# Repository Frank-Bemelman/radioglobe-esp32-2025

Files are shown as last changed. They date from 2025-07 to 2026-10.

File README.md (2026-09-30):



# radioglobe-esp32-2025
Radio Globe using ESP32S3 and Waveshare round touch LCD 2.1 inch<br><br>
UPDATE 29-SEP-2026<br>Changed the file playing progress bar into a slider bar. With this you can move backward/forward through the file playing.<br><br>
UPDATE 21-SEP-2026<br>Improved accuracy of progress bar, compensating for embedded artwork and metadata in music files.<br><br>
UPDATE 19-SEP-2026<br>Added a progress bar for playing files from SD card.<br><br>
UPDATE 5-SEP-2026<br>Several bug fixes and many improvements behind the scenes.<br><br>
UPDATE 2-AUG-2026<br>Improvements regarding fetching timezone(s) and updating the country flags. Should all be a little snappier now.<br><br>
UPDATE 1-AUG-2026<br>Added a new fun feature. When you touch the weather icon, a flight radar screen is shown, with airplanes in that area. Not much particulary usful, but just for fun.<br><br>
UPDATE 27-JUL-2026<br>New station150K.json file upload. Removed all station url's that are no longer active. This also improves the experience with the globe, no more skipping of stations that are no longer active. Used a long running script to test all url's.<br><br>
UPDATE 15-JUL-2026<br>Improved handling of retrieving timezone and geolocation. Race conditions could occur, now hopefully solved. Battery percentage indicator, better than that silly voltage level. <br><br>
UPDATE 12-JUL-2026<br>Automatic Auto Power Off. If you only set the volume to 0, the globe keeps streaming in the background. Which is a waste of bandwidth, for you and for the radio station. So, after 5 minutes, the globe switches off and the clock is shown. Also, after 8 hours normal playing but without any user interaction, the globe will turn the volume down and switches off silently.<br><br> 
UPDATE 7-JUL-2026<br>Switching between Radio and SD music files, can now be done by long pressing the RADIO GLOBE / MUSIC GLOBE text on the main screen. When playing SD card files, the actual path GLOBEMUSIC/xxxx is shown.<br><br>
UPDATE 5-JUL-2026<br>Added a Globe webserver to make it easier to add/delete music MP3 files. Navigate to radioglobe-XX.local where XX is the serialnumber of the globe.<br><br>
UPDATE 3-JUL-2026<br>Fixed a FTP bug as it refused to work with filenames containing single quotes<br><br>
UPDATE 2-JUL-2026<br>
Added FTP servers for globe and puck. For the puck, activate it with secret code BOBOB in setup menu. IP address will be shown once FTP server is launched. Use Filezilla, plain FTP, user globe password globe, transfer settings default, limit max connections 1.<br><br>
UPDATE 1-JUL-2026<br>
New stations150K.json file for the puck SD card. After you replace it, rebuild the database, in puck menu.<br><br>
UPDATE 1-JUL-2026<br>Added the ESP32_VS1053_Stream library files in the Arduino RADIOGLOBE-GLOBE project folder - these are slightly modified<br><br>
UPDATE 30-JUN-2026<br>Added auto update feature -> long press serial number in setup menu for auto update globe and puck<br><br>
UPDATE 24-MRT-2026<br>Added lots of features, worldmap, clock, weather status, currency exchange<br><br>
UPDATE 15-JULY-2025<br>Lots of improvements made. Most stations now play without issues. Happy with the result.<br><br>
UPDATE 6-JULY-2025<br>It actually works! Performance is improved, few bugs, some extras. <br><br>
UPDATE 1-JULY-2025<br>It actually works! Performance is perhaps not perfect but certainly acceptable.<br><br>

Not a small project, will take a lot of your time and possibly quite some frustration along the way. Just a gentle warning.

The idea of a 'Radio Globe' is not mine. I was inspired by the works of Jude Pullen. His brilliant design can be found here:
https://github.com/DesignSparkRS/RadioGlobe

Since I am more of an ESP32 guy, I decided to do a complete redesign. New design of 3d printable parts, which you find in de fusion-3d folder here.
You can use Fusion to select the body you want to print on your 3d printer. Or edit them if you wish. I am not very matured in Fusion, so the Fusion timeline is a nice mess.

The globe uses two ESP32 constantly talking to each other using ESPNOW. 

The first ESP32 is in the base of the globe, and deals with actual streaming of a internet radio station, encoders for the coordinates.
It also retrieving the timezone when new coordinates/position is chosen. The timezone is then sent back to the display puck.

The other ESP32 is part of the display puck. I used a Waveshare touch display 2.1 inch. The display puck deals
with volume control, display of what is going on, like coordinates, local time, station name, what song is playing etc. 
It communicates with the Globe's ESP32, using ESPNOW. It receives the exact coordinates NS and EW, remaps them 
as the globes you can buy aren't very accurate. It sends the remapped coordinates back to the globe. Together with the
remapped coordinates, it sends a radiostation url. The urls are stored on a micro SD card. 

There are two directories with source files. One for the globe and one for the display. It is all based on Arduino IDE 2.3.10

Essential hardware for the globe:<br/>
ESP32S3-N16R8 
MP3 decoder -> https://www.aliexpress.com/item/32893187079.html<br/>
2x magnetic encoder AS5600
<br/>
Essential hardware for the display:<br/>
ESP32S3 Waveshare 2.1 inch LCD -> https://www.aliexpress.com/item/1005008679530480.html<br/>
Lithium battery -> https://www.aliexpress.com/item/1005008575678945.html<br/>
2x Magnets 10mmx2mm
Pogo 3 pin connector -> https://www.aliexpress.com/item/1005007457425590.html<br/> 
MicroSD card -> I used a 32GB one<br/>

1) The 3D files can be send to jlcpcb.com. Best choices for base and puck are black nylon. For the main globe support, transparent resin is nice, but you need to spray them with a UV blocking varnish, as they tend yellow very quickly when placed near a window. The counterweight to be printed in metal, and if you want to use the truss as a touch sensor, also in metal.
   
3) Prepare the SD card and fill it with the files provided in SDCARD. This is for the database with 150K stations and two folders with images for the flags of all countries in the world. Insert the card in the Waveshare display. Once you have loaded the software into the Waveshare, you can create a presorted database arrangement in a folder structure on the SD card. This takes perhaps 45 minutes, but then you're good to go.

4) Prepare the ESP32 module with the software for the globe itself. Compile in Arduino IDE, don't forget to fill the secrets.h file with your wifi SSID and password.

5) Get an API key at Google Developer platform, for the TimeZone API and Geo Geocoding API, both use the same API key. It is used to find the right timezone for the clock, and also to get the right two-letter country code to be able to display the right country flag. It is a bit of hassle, but very worthwhile. And it is free.

I don't plan to give a step-by-step instruction here. That is too much effort and I don't know if there is a lot of interrest in this project. But if you start with it, just ask, simply raise as an issue. In which case I may elaborate a bit more.

Cheers,
Frank

[work in progress]

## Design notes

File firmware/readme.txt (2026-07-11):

Latest version has an easier auto update function. It will signal a new update is available, if the cogwheel setup button is red. 
Go into settings on the puck, long press the serial number and it will upgrade both globe and puck, using the bin files from the release. 
First the globe upgrades automatically, then the puck will upgrade also.
The puck display goes black during the upgrade, just hang in there for a few minutes - it will reboot after a few minutes.

HOWEVER!!! If your version does NOT have the auto-update feature yet, it takes a bit more work.
Good news is, you only have to do this once.

1) download the three bin files for globe (firmware) and puck (firmware and new partition table) as found in the release.
   These can all be uploaded using a chrome browser on PC and a webtool
2) Browse to: https://thelastoutpostworkshop.github.io/ESPConnect/
3) Connect Puck, use the blue connect button, select the USB port, and connect.
   Select Flash Tools on the left.
4) First flash the new partition file for the puck. Load it in the flashtool, select Recommended Offsets -> Partition Table • 0x8000 • 4 KB
   Hit the large FLASH FIRMWARE bar/button.
5) Load the RadioGlobe-Display.bin, select Recommended Offsets -> App0 0x10000 4MB
   Hit the large FLASH FIRMWARE bar/button.
6) Disconnect Puck, reset it with side button.
7) Check in the puck setup if the build date has been adjusted. If not, try again with App1 0x410000 4MB

8) Connect the Globe ESP32S3 to your PC. Use the blue connect button, select the USB port, and connect.
9) Load the RadioGlobe-Globe.bin, select Recommended Offsets -> App0 0x10000 3MB
   Hit the large FLASH FIRMWARE bar/button. 
10) Disconnect Globe and reset globe (power off-on).
11) Check in the puck setup if the globe build date has been adjusted. If not, try again with App1 0x310000 3MB

From now on, you can update automatically, no more fiddling with cables.
Everytime you power down/up the globe using the puck, it will check for an update and the cogwheel will turn red if there is one available.
You can also force a check for new updates, by long pressing the serial number in the setup menu.
During an automatic update the puck goes black, don't worry, it will come back after 2-3 minutes.

Enjoy & Good luck!

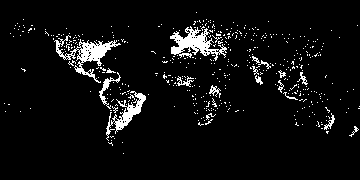
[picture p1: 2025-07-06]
source/squareline/assets/stationsmap150K.png

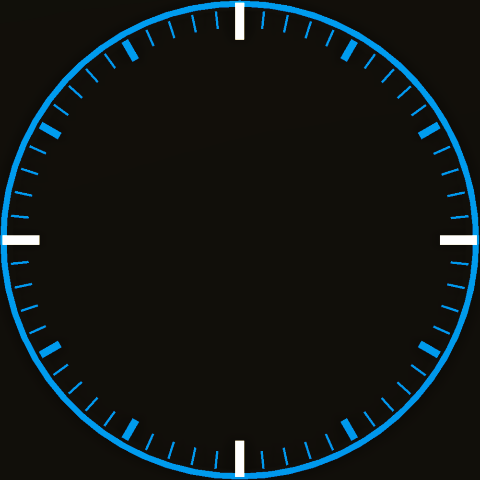
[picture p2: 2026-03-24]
source/squareline/assets/clock480.png

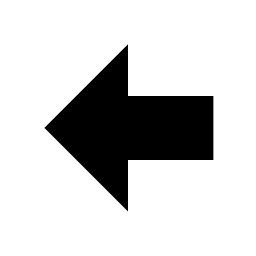
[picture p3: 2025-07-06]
source/squareline/assets/arrow_left_bold.png

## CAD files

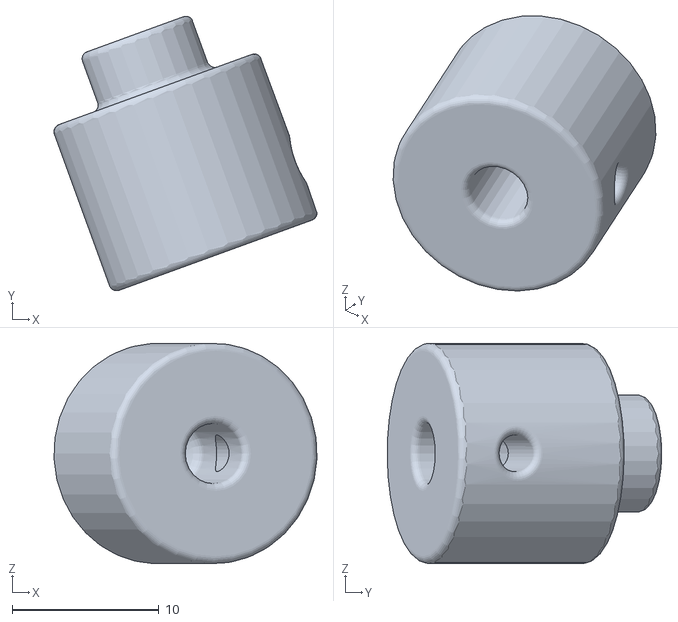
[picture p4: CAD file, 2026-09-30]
fusion-3d/main-shaft-magnet-holder.stl
17.9 x 18.7 x 15.0

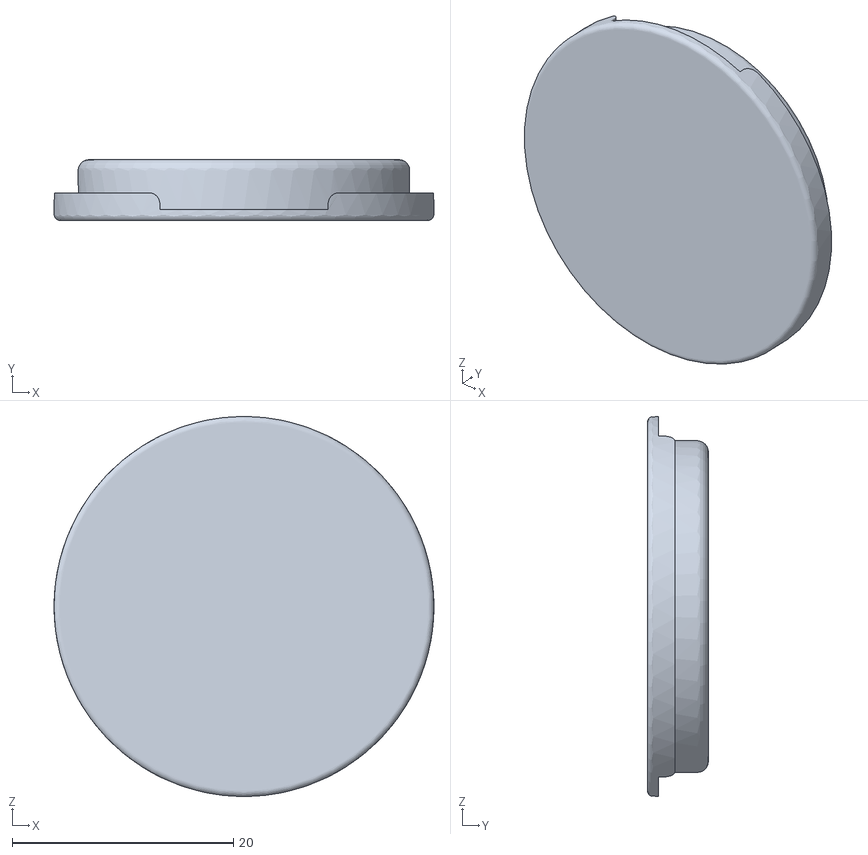
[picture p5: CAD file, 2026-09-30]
fusion-3d/globe-main-support-lid.stl
34.3 x 5.50 x 34.3

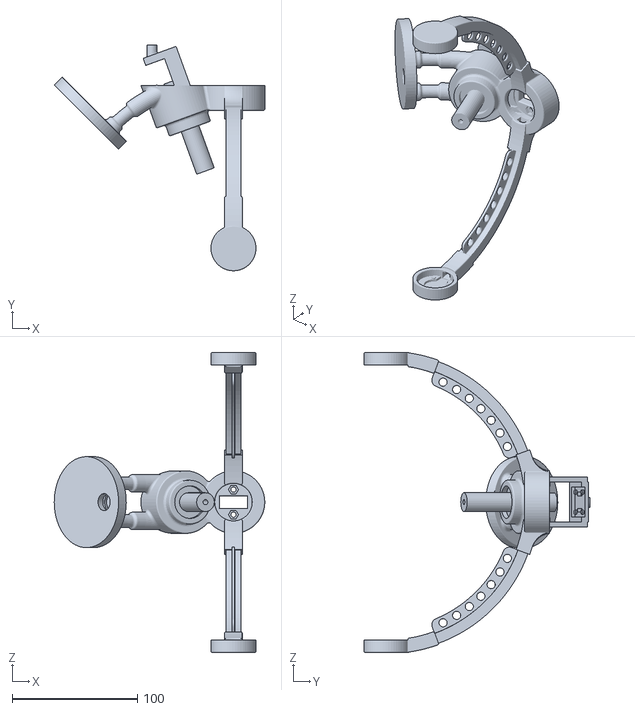
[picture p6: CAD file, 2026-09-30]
fusion-3d/globe-main-support.stl
168.0 x 180.0 x 239.4

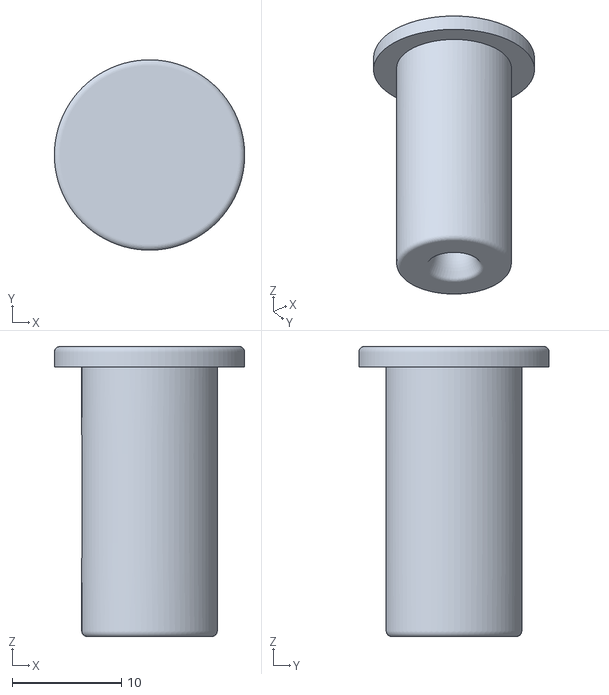
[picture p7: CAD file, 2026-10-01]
fusion-3d/globe-bushing-top.stl
17.4 x 17.4 x 26.5

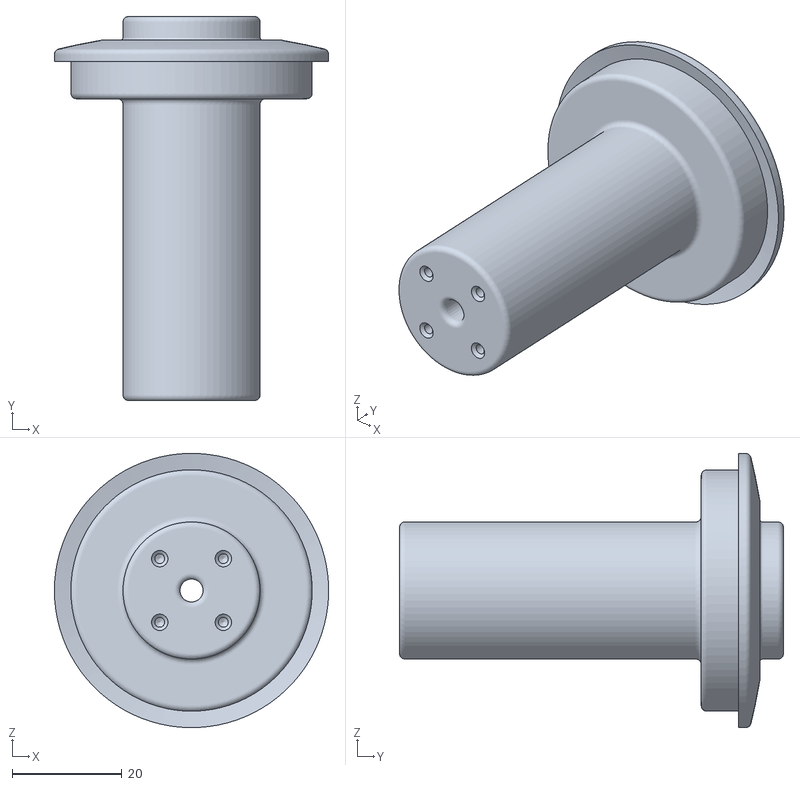
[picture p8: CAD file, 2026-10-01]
fusion-3d/globe-bushing-bottom.stl
50.0 x 70.0 x 50.0

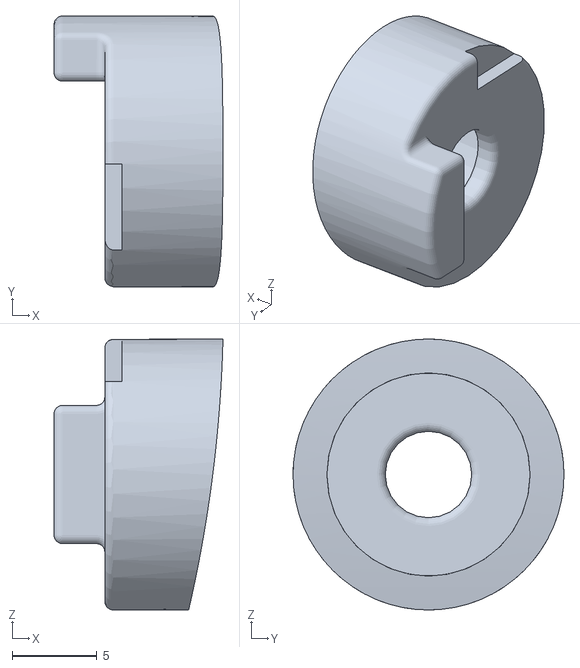
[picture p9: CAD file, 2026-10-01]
fusion-3d/audio-jack-spacer.stl
9.97 x 16.0 x 16.0

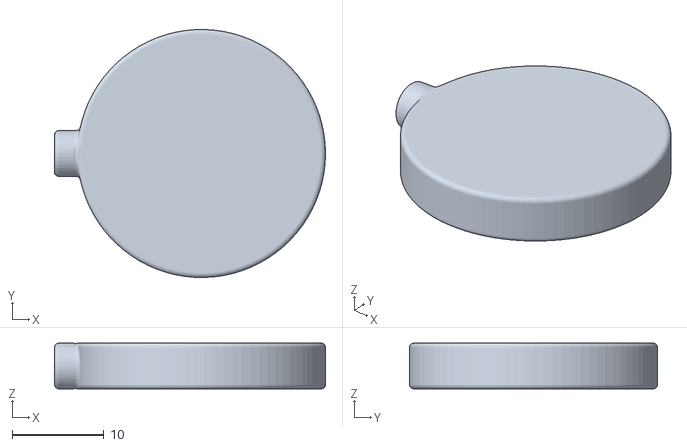
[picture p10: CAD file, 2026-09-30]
fusion-3d/globe-counterweight-metal.stl
29.5 x 27.0 x 5.00

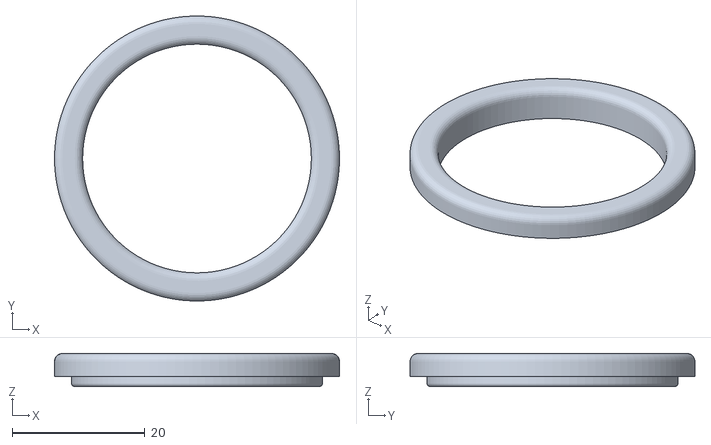
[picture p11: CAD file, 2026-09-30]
fusion-3d/speaker-2x-bezel.stl
43.0 x 43.0 x 5.00

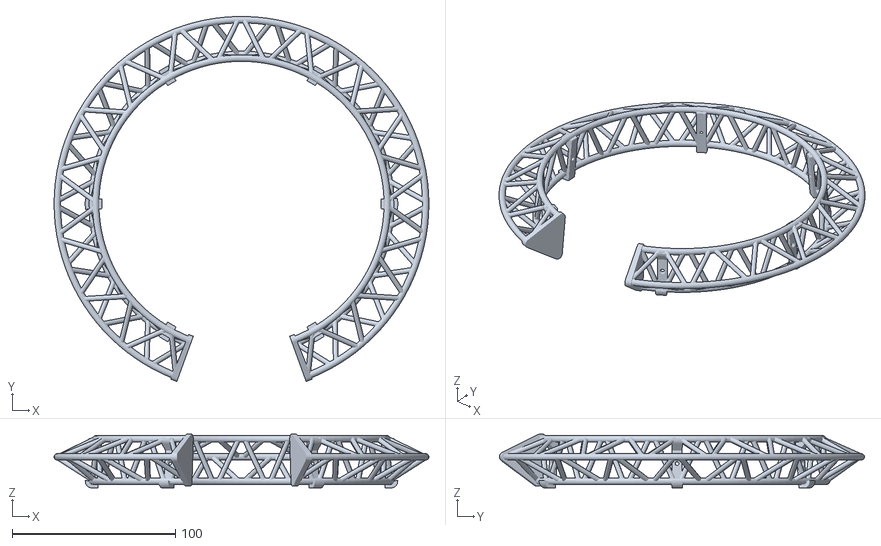
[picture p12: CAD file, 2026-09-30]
fusion-3d/base-truss-metal.stl
229.9 x 223.9 x 33.1

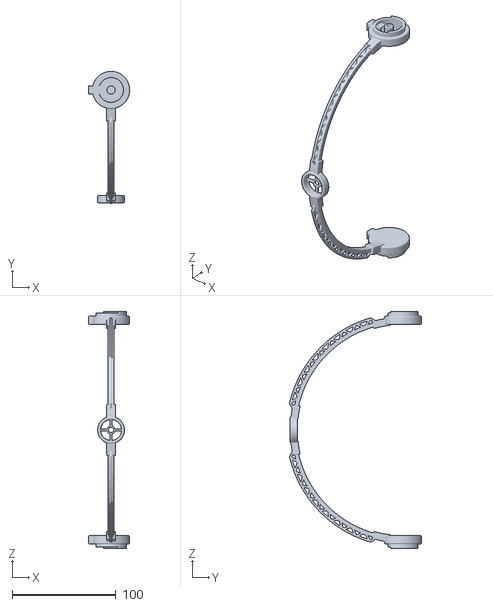
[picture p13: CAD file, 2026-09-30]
fusion-3d/globe-search-arm.stl
40.0 x 127.8 x 229.0

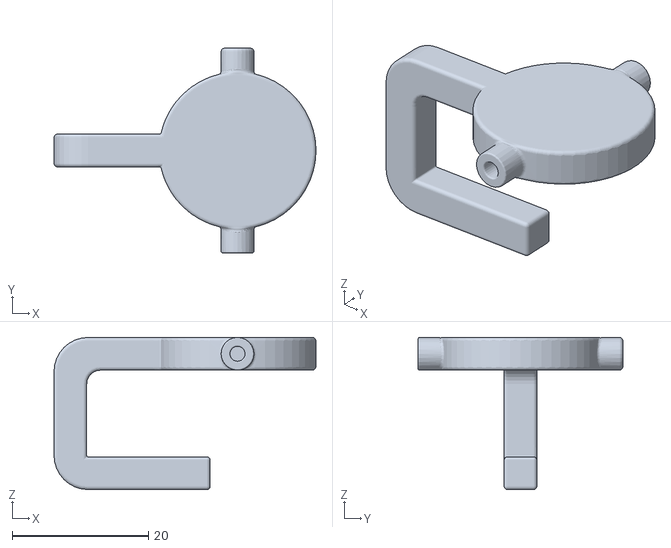
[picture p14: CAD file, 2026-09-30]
fusion-3d/clamp-left.stl
38.4 x 30.0 x 22.3

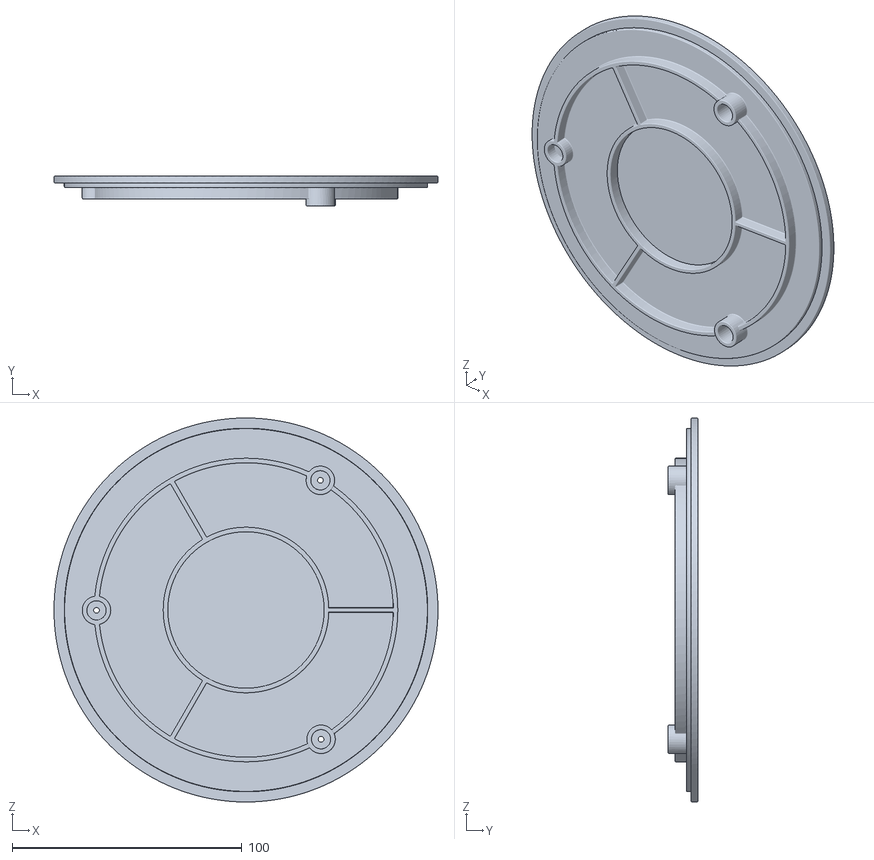
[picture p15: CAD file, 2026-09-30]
fusion-3d/bottom-lid.stl
167.0 x 13.0 x 167.0

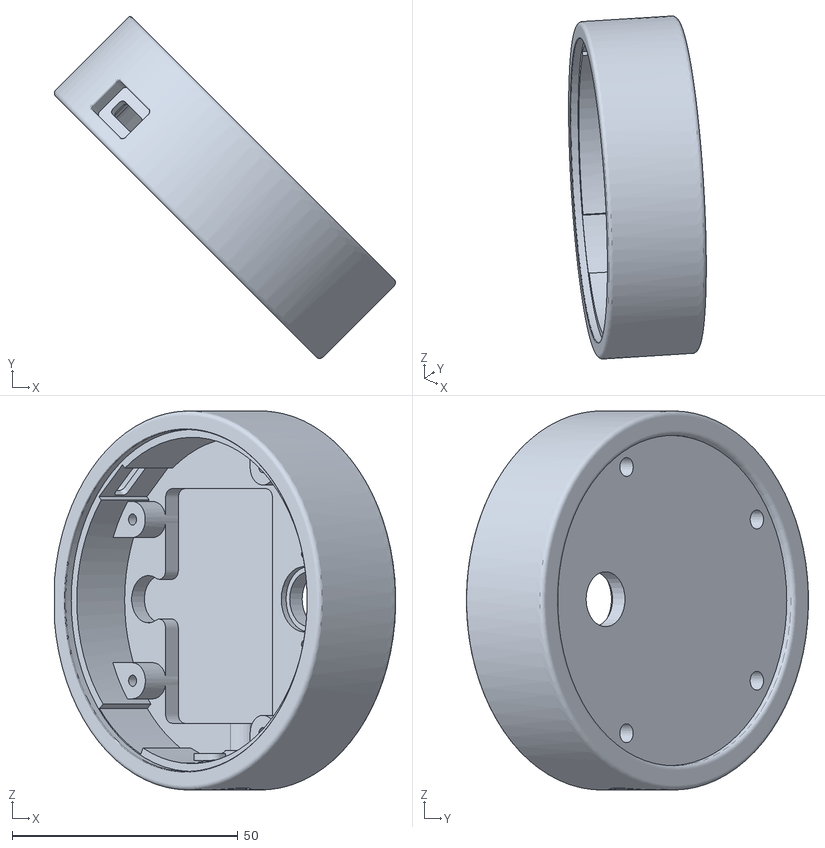
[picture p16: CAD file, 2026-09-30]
fusion-3d/display-puck.stl
75.6 x 75.8 x 84.0

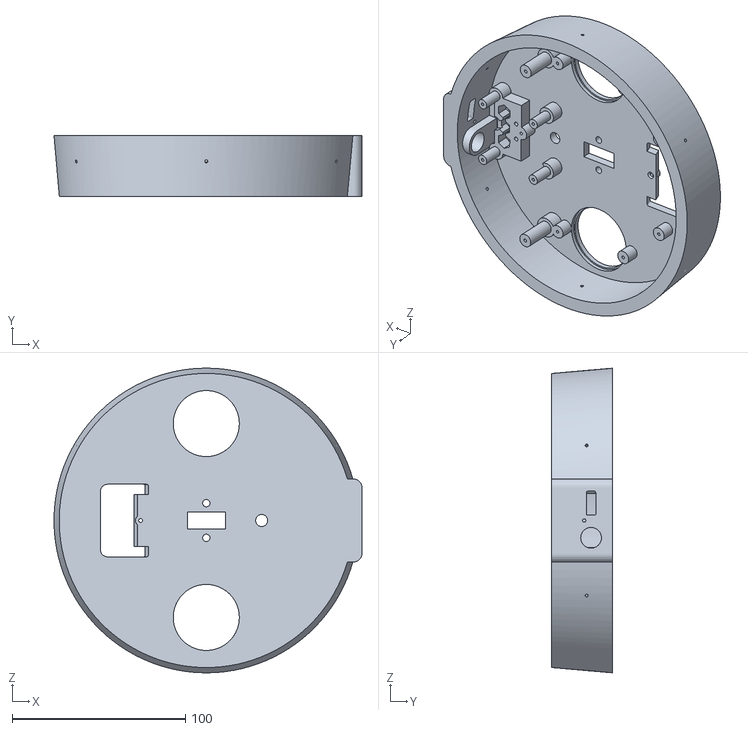
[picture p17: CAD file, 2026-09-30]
fusion-3d/base.stl
178.0 x 35.0 x 176.1

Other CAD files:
fusion-3d/clamp-right.stl

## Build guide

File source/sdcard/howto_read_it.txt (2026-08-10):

Why replacing it? Newer stations150K.json files have less dead stations. Makes the globe snappier if it does not have to try stations that no longer exist.

There are two ways of doing it. You can open the puck and fiddle with the SD card or use the FTP server.

Using the FTP server saves you the hassle of opening the puck.

1) Install Filezilla FTP on your PC.
2) On the puck, enter secret code BOBOB. This will launch a FTP server and IP address is shown
3) Using Filezilla, use sitemanager, create a new site, for host use the IP address shown on puck.
4) IMPORTANT - under transfer settings, limit number connections to 1.
5) User&password is globe, globe.
6) Delete the stations150K.json file on the puck.
7) Reset/reboot puck, it will then delete all N/S direcotries - their content is outdated. This can easily take 10 minutes, there are thousands of directories to delete.
8) Restart the FTP server on puck, BOBOB, and upload the new stations150K.json
9) Enter secret code globe, go in setup again, database, and rebuild the database.
10) All done.

All done is well done.

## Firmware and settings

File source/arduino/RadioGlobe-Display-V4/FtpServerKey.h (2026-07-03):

/*
 * FtpServer Arduino, esp8266 and esp32 library for Ftp Server
 * Derived form Jean-Michel Gallego version
 *
 * AUTHOR:  Renzo Mischianti
 *
 * https://www.mischianti.org/2020/02/08/ftp-server-on-esp8266-and-esp32
 *
 */

/*******************************************************************************
 **                                                                            **
 **                         SETTINGS FOR FTP SERVER                            **
 **                                                                            **
 *******************************************************************************/

#ifndef FTP_SERVER_CONFIG_H
#define FTP_SERVER_CONFIG_H

// Uncomment to enable printing out nice debug messages.
// #define FTP_SERVER_DEBUG
// #define FTP_ADDITIONAL_DEBUG

// Define where debug output will be printed.
#define DEBUG_PRINTER Serial

#define STORAGE_SDFAT1 		1 	// Library SdFat version 1.4.x
#define STORAGE_SDFAT2 		2 	// Library SdFat version >= 2.0.2
#define STORAGE_SPIFM  		3 	// Libraries Adafruit_SPIFlash and SdFat-Adafruit-Fork
#define STORAGE_FATFS  		4 	// Library FatFs
#define STORAGE_SD 			5 	// Standard SD library (suitable for Arduino esp8266 and esp32
#define STORAGE_SPIFFS 		6 	// SPIFFS
#define STORAGE_LITTLEFS 	7 	// LITTLEFS
#define STORAGE_SEEED_SD 	8 	// Seeed_SD library
#define STORAGE_FFAT  		9 	// ESP32 FFAT
#define STORAGE_SD_MMC		10 	// SD_MMC library

#define NETWORK_ESP8266_ASYNC 	(1)
#define NETWORK_ESP8266 		(2) 	// Standard ESP8266WiFi
#define NETWORK_ESP8266_242 	(3) 	// ESP8266WiFi before 2.4.2 core
#define NETWORK_W5100 			(4)		// Standard Arduino Ethernet library
#define NETWORK_ETHERNET		(4)		// Standard Arduino Ethernet library
#define NETWORK_ENC28J60 		(5) 	// UIPEthernet library
#define NETWORK_ESP32 			(6) 	// Standard WiFi library
#define NETWORK_RP2040_WIFI		(15) 	// Raspberry Pi Pico W standard WiFi library
#define NETWORK_ESP32_ETH 		(7)		// Standard ETH library
#define NETWORK_WiFiNINA 		(8)		// Standard WiFiNINA library
#define NETWORK_SEEED_RTL8720DN (9) 	// Standard SEED WiFi library
#define NETWORK_ETHERNET_LARGE 	(10)
#define NETWORK_ETHERNET_ENC 	(11)	// EthernetENC library (evolution of UIPEthernet
#define NETWORK_ETHERNET_STM 	(12)
#define NETWORK_UIPETHERNET 	(13)	// UIPEthernet library same of NETWORK_ENC28J60
#define NETWORK_ETHERNET_GENERIC	(14)	// Ethernet generic

// esp8266 configuration
#ifndef DEFAULT_FTP_SERVER_NETWORK_TYPE_ESP8266
	#define DEFAULT_FTP_SERVER_NETWORK_TYPE_ESP8266 	NETWORK_ESP8266
	#define DEFAULT_STORAGE_TYPE_ESP8266 				STORAGE_LITTLEFS
#endif
// esp32 configuration
#ifndef DEFAULT_FTP_SERVER_NETWORK_TYPE_ESP32
	#define DEFAULT_FTP_SERVER_NETWORK_TYPE_ESP32 		NETWORK_ESP32
	#define DEFAULT_STORAGE_TYPE_ESP32 					STORAGE_SD_MMC
	/**
To use Ethernet.h with esp32 fix would be to change in Ethernet.h the line
class EthernetServer : public Server {
to
class EthernetServer : public Stream {

or

in \esp32\2.0.6\cores\esp32\Server.h
A workaround is to change line 28 of the ESP32 core's Server.h from:
    virtual void begin(uint16_t port=0) =0;
to
    virtual void begin() =0;
However, the last one, that will break anything that uses the ESP32 WiFi library's WebServer class.

https://github.com/arduino-libraries/Ethernet/issues/193
https://github.com/arduino-libraries/Ethernet/issues/88
	 *
	 */
#endif
// Standard AVR Arduino configuration
#ifndef DEFAULT_FTP_SERVER_NETWORK_TYPE_ARDUINO
	#define DEFAULT_FTP_SERVER_NETWORK_TYPE_ARDUINO 	NETWORK_W5100
	#define DEFAULT_STORAGE_TYPE_ARDUINO 				STORAGE_SD
#endif
// STM32 configuration
#ifndef DEFAULT_FTP_SERVER_NETWORK_TYPE_STM32
	#define DEFAULT_FTP_SERVER_NETWORK_TYPE_STM32 		NETWORK_W5100
	#define DEFAULT_STORAGE_TYPE_STM32 					STORAGE_SDFAT2
#endif
// Raspberry Pi Pico (rp2040) configuration
#ifndef DEFAULT_FTP_SERVER_NETWORK_TYPE_RP2040
    #define DEFAULT_FTP_SERVER_NETWORK_TYPE_RP2040 		NETWORK_RP2040_WIFI
	#define DEFAULT_STORAGE_TYPE_RP2040					STORAGE_LITTLEFS
#endif

// Arduino SAMD21 like Arduino MKR Nano 33 IoT or Wio Terminal
#ifndef DEFAULT_FTP_SERVER_NETWORK_TYPE_ARDUINO_SAMD
// Wio Terminal
//	#define DEFAULT_FTP_SERVER_NETWORK_TYPE_SAMD NETWORK_SEEED_RTL8720DN
//	#define DEFAULT_STORAGE_TYPE_SAMD STORAGE_SEEED_SD

// Arduino SAMD
	#define DEFAULT_FTP_SERVER_NETWORK_TYPE_SAMD 		NETWORK_WiFiNINA
	#define DEFAULT_STORAGE_TYPE_SAMD 					STORAGE_SD
#endif

#define UTF8_SUPPORT

//#define SD_CS_PIN 4
// Disconnect client after 5 minutes of inactivity (expressed in seconds)
#ifndef FTP_TIME_OUT
	#define FTP_TIME_OUT  5 * 60
#endif


// Wait for authentication for 10 seconds (expressed in seconds)
#ifndef FTP_AUTH_TIME_OUT
	#define FTP_AUTH_TIME_OUT 10
#endif

// Uncomment to enable dynamic transfer buffer
#if defined(ESP32) || defined(ESP8266)
	#define DYNAMIC_TRANSFER_BUFFER
#endif

// Size of file buffer for read/write
// Transfer speed depends of this value
// Best value depends on many factors: SD card, client side OS, ...
// But it can be reduced to 512 if memory usage is critical.
#ifndef FTP_BUF_SIZE
  // Set sensible defaults per piattaforma to maximize throughput without
  // exhausting RAM. Users can still override these by defining FTP_BUF_SIZE
  // before including this header.
  #if defined(ESP32) || defined(ARDUINO_ARCH_ESP32)      // lots of RAM, faster I/O
    #define FTP_BUF_SIZE 8192                            // FB was 2048 changed to 8192 
  #elif defined(ESP8266) || defined(ARDUINO_ARCH_ESP8266) // less RAM than ESP32
    #define FTP_BUF_SIZE 1024
  #elif defined(__AVR__)                                  // classic AVR (Uno, Nano)
    #define FTP_BUF_SIZE 512
  #elif defined(ARDUINO_ARCH_STM32) || defined(STM32F1)   // STM32 boards - moderate RAM
    #define FTP_BUF_SIZE 1024
  #elif defined(ARDUINO_ARCH_RP2040) || defined(PICO_RP2040) // Raspberry Pi Pico W
    #define FTP_BUF_SIZE 2048
  #elif defined(ARDUINO_ARCH_SAMD)                        // SAMD (MKR, Nano 33)
    #define FTP_BUF_SIZE 1024
  #else
    // Generic default if architecture not detected
    #define FTP_BUF_SIZE 1024
  #endif
#endif

#endif // FTP_SERVER_CONFIG_H

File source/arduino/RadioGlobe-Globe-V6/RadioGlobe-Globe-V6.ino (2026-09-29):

// in arduino library manager........
// install libs as shown here https://randomnerdtutorials.com/esp32-wi-fi-manager-asyncwebserver/
// this is for the wifi manager portal

// libraries needed in Arduino ide
// Arduinojson by Benoit - v7.4.3
// https://github.com/baldram/ESP_VS1053_Library download zip file and install
// AS5600 by Rob Tilaart - v0.6.7
// Adafruit Neopixel 1.15.5
// WiFiManager by tzapu V2.0.17
// Async TCP by ESP32Async V3.50
// ESPAsyncWebServer by ESP32Async V3.12.0 
// ESP_SSLClient by Mobitz V 3.1.3
// home-assistant-integration Version  by Dawid 2.1.0
// ESP32_VS105_Stream by Cellie, files placed in arduino sketch folder

// arduino ide settings 
// esp32 3.1.11 board library
// esp32s3 dev module
// tools -> flash size 16MB
// tools -> partition 16MB 3MB APP 9.9MB FATFS
// tools -> PSRAM OPI PSRAM 

// 30 JUN 26 - auto update refinements
// 27 JUN 26 - added auto update from github
// 25 MAY 26 - in setup_esp_now() make it just a station, not an acces point
// 24 MAY 26 Added BT switch to mqtt for HA
// 21 MAY 26 ESP32_VS1053_Stream updated
// 19 MRT 26 FEATURE Sd card connections added and tested, acces to SD card works, no functionality added though
// 17 MRT 26 IMPROVED Turn of amplifiers when stream stops, or after playing a soundbite
// 9 MRT 26 - GetGeolocationData() local arrys enlarged, was crashing on weird thai town names
// other libraries and updates
// 25feb2026 -> AS5600@0.6.6 (was AS5600@0.6.5)
// reminder features 
// 14FEB26 -> has wifi channel updated by globe wifi connection
// 18APR26 -> added ftp server for SD card acces, see https://github.com/Annabel369/ESP32FTPServer (works but is very slow, practically not very useful) user guest, password guest
// 25JUN26 -> added update routines 

#include <Arduino.h>

#define BUILD_LABEL "Globe Build"
// make this -> Globe Build Jun 23 2026 - 21:08:50
#define BUILD_TIMESTAMP  BUILD_LABEL " " __DATE__ " - " __TIME__
#define BUILD_TIMESTAMP_ONLY __DATE__ " - " __TIME__
const char build_label[] PROGMEM =  BUILD_LABEL;
const char build_timestamp[] PROGMEM =  BUILD_TIMESTAMP;
const char build_timestamp_only[] =  BUILD_TIMESTAMP_ONLY;
extern uint8_t UpdateFirmware(uint8_t state); // start with 1 for a full date/time check and update
extern bool CheckForNewGlobeUpdate(void);
bool UpdateAvailable = false;

#include <ArduinoJson.h>
#include <ArduinoJson.hpp>
#include <ESPmDNS.h>
#include <WiFi.h>
//#include "ESP32FtpServer.h"
#include "SimpleFTPServer.h"
#include <esp_wifi.h>
#include <WiFiClient.h>
//#include <ESP32_VS1053_Stream_V4.h>  // https://github.com/CelliesProjects/ESP32_VS1053_Stream
#include "ESP32_VS1053_Stream.h"  // https://github.com/CelliesProjects/ESP32_VS1053_Stream
// keeping the ESP32_VS1053_Stream in my sketch folder now, to make it easier ot mess around with
// changed in ESP32_VS1053_Stream.h around line 15-16
// the original lower values often give connection refused for more remote locations
// #define VS1053_CONNECT_TIMEOUT_MS 5000 // FB was 500 FB
// #define VS1053_CONNECT_TIMEOUT_MS_SSL 5000 // FB was 1000
#include "franks-esp-now.h"
#include "countrycodes.h" 
#include "mp3_startup.h"
#include "mp3_shutdown.h"
#include "mp3_voice_prompts.h"
#include "mp3_radio_tuning.h"
#include "mp3_happy_ping.h"

#include "..\secrets.h"
// as defined in ..\secrets.h
// char SSID [32] = "YOUR-SSID";
// char PASSWORD[32] = "YOUR-WIFI-PASSWORD";
// char google_api_key[] = "YOUR-API-KEY"; // free, get your own at google developer platform, used for timezone retrieval, replace first 4 letters AIza in !!!!
// to avoid a verbatim copy of api key in compiled binary 
#include "AS5600.h"
#include "Wire.h"
#include "esp_bt.h"


#define COPY_LOG_OFF

// esp32s3-16r8 has a nice pixel led which we will use to indicate Wifi portal active and more
// note -> there is a solder bridge next to the pixel led, you have to put a small solder blob on that to make it work
#include <Adafruit_NeoPixel.h> 
#define PIN 48
#define NUMPIXELS 8
Adafruit_NeoPixel pixels(NUMPIXELS, PIN, NEO_GRB + NEO_KHZ800);

// https://randomnerdtutorials.com/esp32-s3-devkitc-pinout-guide/
// VS1053 sound module esp32-S3-N16R8 pin arrangement HSPI (SPI2)
#define SPI_MOSI_PIN 11 // white
#define SPI_CLK_PIN 12  // green
#define SPI_MISO_PIN 13 // orange

#define VS1053_CS 16 // grey
#define VS1053_DREQ 9 // yellow 
#define VS1053_DCS 10 // blue
#define VS1053_RESET 15 // brown

//#include "FS.H"
#include "SD.h"
#include "SPI.H"

// SD card module, simplest model, sharing same pins as VS1053 except CS is different -> works but stutters when playing from SD
//#define SPI_MOSI_PIN 11 // green (pin 3 SD module)
//#define SPI_CLK_PIN 12  // yellow (pin 4 SD module)
//#define SPI_MISO_PIN 13 // orange (pin 5 SD module)

// Tried, but cam't make it work with 2nd SPI/VSI/HSPI -> keep rebooting
//#define SD_MOSI 35 // green (pin 3 SD module)
//#define SD_CLK 36  // yellow (pin 4 SD module)
//#define SD_MISO 37 // orange (pin 5 SD module)

// later PCB boards have the SD card integrated in the design
#define SD_MOSI 41 // green (pin 3 SD module)
#define SD_CLK 40  // yellow (pin 4 SD module)
#define SD_MISO 38 // orange (pin 5 SD module)
#define SD_CS 39 // blue (pin 2 SD module)
// brown GND (pin 6 SD module)
// red +3V3 (pin 1 SD module)



SPIClass *hspi = 0;

ESP32_VS1053_Stream stream;
//VS1053 chunkplayer(VS1053_CS, VS1053_DCS, VS1053_DREQ); // made a playChunk member in ESP32_VS1053_Stream library

// AS5600 encoders esp32-S3-N16R8 pin arrangement
const int SCL_1 = 4; // &wire as5600_lat grey NS LAT
const int SDA_1 = 5; // &wire as5600_lat brown NS LAT
const int SCL_2 = 6; // &wire as5600_lon grey EW LON
const int SDA_2 = 7; // &wire as5600_lon brown EW LON

#define MUTE_AMPLIFIERS 14 // pin number
#define SPEAKERS_OFF 0
#define SPEAKERS_ON 1
#define SPEAKERS_DELAYED_OFF 3

AS5600 as5600_lat(&Wire); // NS LAT Encoder
AS5600 as5600_lon(&Wire1); // EW LON Encoder

static uint32_t startMillis;
static uint32_t lapMillis;
static uint32_t currentMillis;
static uint32_t ConnectedInMillis;
static uint32_t StationConnectedAtMillis;


int16_t PrevTick = 0;
bool bPowerStatus = true;
bool bVolumeToneControlsActive = false;

bool bUpAndRunning = false;
bool bSetupCompleted = false;
bool bEncoderNewPosition = false;
bool bEncoderKillStation = false;
bool bGlobeStable = false;
uint16_t Timer100msSerialCanBeOpened = 0; // set to 5 seconds after 5 taps on touch
uint16_t Timer100msSerialIsOpen = 0; // set to 30 seconds after speaker switch pressed
uint16_t SpeakerOffAfter25mS = 0;

char TargetUrl[QUEUEMESSAGELENGTH] = ""; // most recent url requested by display
char ActiveUrl[QUEUEMESSAGELENGTH] = ""; // most recent url connected to
char PrevUrl[QUEUEMESSAGELENGTH] = ""; // most recent url connected to


bool Tuning = false;
bool bSomethingPlays = false;

#define SPEAKER_TOGGLE_PIN 21 // pushbutton behind globe support for speaker toggle and bleutooth connect
#define BT_CONNECT_PIN 17 // output connected to BT module to force a BT connect
#define BT_POWER_PIN 2
#define PORTALSWITCH_PIN 20 // pushbutton located on the back, short press  opens portal to connect to smartphone and configure wifi and puck mac, long press > 3 seconds is resets,all settings

#include <EEPROM.h>
#define EEPROM_SIZE 512
struct eepromData 
{ int16_t OffsetLat;
  int16_t OffsetLon;
  uint16_t ee_volume; // 0-100 can be changed by display puck
  uint16_t ee_bass; // 0-f can be changed by display puck
  uint16_t ee_treble; // 0-f can be changed by display puck
  uint16_t ee_internal_speakers; // 0-f can be changed by display puck
  char HomeCountryCode[3]; // used as base for exchange rate 
  char ssid[32];
  char password[32];
  char google_api_key[64];
  uint8_t ee_puckmac[6];
  uint8_t ee_mqttserver_ip[4];
  uint32_t magicnumber;
  uint32_t serialnumber;
  uint16_t btmodule_installed;
  uint16_t btmodule_switchable;
  uint16_t btmodule_power_on;
  char open_weather_map_api_key[64];
  uint16_t globe_sd_gb;
  char spare_data[];
};
eepromData GlobeSettings; 

uint8_t rtone[4] = {0, 3, 14, 0}; // tone control register of VS1053 responding to display controls for bass & treble, values of 0-15

uint32_t RefreshRatesCountDownTimer = 0;
uint16_t IgnoreMqqtUpdates = 0;

uint8_t GlobeMac[6];
uint8_t PuckMac[] = {0x00, 0x00, 0x00, 0x00, 0x00, 0x00};
int16_t bMqttActivated = 4567;

unsigned int PresetRequestFromHA = 0;
char ActiveStationTitle[256] = "";
char ActiveSongTitle[256] = "";

char MetaDataSongTitle[256] = "";
char MetaDataRadioStation[256] = "";


void TaskTouch(void * pvParameters);
void PixelUpdate(uint16_t mode, uint32_t color1, uint32_t color2, uint16_t msek);

char HostName[32];

bool bMusicMode = false;
bool bMusicModePrev = false;

#define MAX(a,b) (((a) > (b)) ? (a) : (b))
#define MIN(a, b) (((a) < (b)) ? (a) : (b))

FtpServer ftp;

extern uint16_t UpdateState;

char VS1053_CallBackLastError[QUEUEMESSAGELENGTH];

extern void setupwebserver(void);


char PrevStreamType[64]="";
char StreamType[64]="";
char StreamCodec[16]="";
char StreamBitrate[16]="";
char StreamFilllevel[16]="";



volatile uint32_t GlobalTicker100mS = 0;
volatile bool bFlag100mS = false; // will always reset to true within 100mS by timer interrupt

void IRAM_ATTR onGlobalTimer100ms(void* arg) {
    GlobalTicker100mS++;
    bFlag100mS = true; 
}

void SetupGlobalTimer100mS(void) {
    const esp_timer_create_args_t timer_args = {
        .callback = &onGlobalTimer100ms,
        .name = "global_100ms_ticker"
    };

    esp_timer_handle_t global_timer;
    esp_timer_create(&timer_args, &global_timer);
    // start timer every 100.000 microseconden -> 100 ms
    esp_timer_start_periodic(global_timer, 100000); 
}

void readMacAddress()
{ esp_err_t ret = esp_wifi_get_mac(WIFI_IF_STA, GlobeMac);
  if (ret == ESP_OK) 
  { Serial.println(BUILD_TIMESTAMP);
    Serial.printf("%02X:%02X:%02X:%02X:%02X:%02X\n",
                  GlobeMac[0], GlobeMac[1], GlobeMac[2],
                  GlobeMac[3], GlobeMac[4], GlobeMac[5]);
  } 
  else 
  { Serial.println("Failed to read Globe MAC address!");
  }
}

bool bPortalOpened = false; // to freeze loop_esp_now(); during portal, so wifi channel is more quiet

// stacksize is standard 8K
// as experiment, tried to increase it to see if it made any differences regarding instabilities I had at a certain moment. 
// can't say it made much difference
// so I took it out again
// 20AUG26 tried back 8, Rad Suravi stutters
// back 16
//SET_LOOP_TASK_STACK_SIZE(16*1024);
//SET_LOOP_TASK_STACK_SIZE(8*1024); // weer eens een tijdje op 8

VS1053 *franks_vs1053;
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
void loop()
{ char message[QUEUEMESSAGELENGTH];
  float GpsNS;
  float GpsEW;
  static String receivedMessage = "";
  static char incomingChar;
  static char text[64];
  static char *p;

  static uint16_t QueueMessageType;
  static char QueueMessage[QUEUEMESSAGELENGTH];
  static uint32_t value_int32t = 0;
  static uint16_t connection_lost_counter;
  static char PreviousUrl[QUEUEMESSAGELENGTH] =""; // holds the url requested by display
  static char StartThisStation[QUEUEMESSAGELENGTH] =""; // holds the url requested by display
  static bool bFirst = true;
  static uint32_t LoopTicker100mS = 0;
  
  static uint32_t nowmillis;
  static uint32_t prevmillis;
  static uint32_t lapmillis;
  static uint32_t lastmillis;

  if(GlobeSettings.globe_sd_gb != 0)ftp.handleFTP();
   
  loop2(); // checks portal button in advanced.ino
  
  lapmillis = millis() - lastmillis;
  if(lapmillis>30)Serial.printf("main loop(); took = %dmS\n", lapmillis);
  prevmillis =  millis();

  
  stream.loop(); // keeps the VS1053 going..
  
  lapmillis = millis() - prevmillis;
  if(lapmillis>100)Serial.printf("stream.loop(); took = %dmS\n", lapmillis);
  prevmillis = millis();

  if(bMqttActivated==1234)loopMQTT();
  
  if(UpdateState) // update check in one step at the time
  { UpdateState = UpdateFirmware(UpdateState);
  } 

  if(bFlag100mS)
  { bFlag100mS = false; 
    LoopTicker100mS = GlobalTicker100mS;
    if(!bPortalOpened && lapmillis<40) // time just spent in stream.loop();
    { //loop_esp_now();
      nowmillis = millis();
      lapmillis = nowmillis - prevmillis;
      if(lapmillis>10)Serial.printf("loop_esp_now(); took = %dmS\n", lapmillis);
      prevmillis = nowmillis;
    }
    if((LoopTicker100mS % 5)==0 && bGlobeStable && !bMusicMode) // every half seconds or so
    { if(strcmp(PrevStreamType, StreamType)!=0)
      { strcpy(PrevStreamType, StreamType);
        AddToQueueForDisplay(StreamType, MESSAGE_STATUS_LINE);
      }
    }
  }  

  if((LoopTicker100mS % 50)==0) // every 5 seconds or so
  { if(WiFi.status() != WL_CONNECTED) 
    { if(connection_lost_counter++>500)
      { Serial.println("Unable to recover Wifi after 2500 seconds...");
        delay(100);
        ESP.restart(); 
      }
      Serial.printf("Reconnecting to Wifi attempt %hu...\n", connection_lost_counter);
      WiFi.disconnect();
      WiFi.mode(WIFI_OFF);
      delay(100); 
      WiFi.mode(WIFI_STA);
      WiFi.setSleep(false); 
      WiFi.begin(GlobeSettings.ssid, GlobeSettings.password);
    }
    else
    { if (connection_lost_counter > 0)
      { AddToQueueForDisplay("WIFI -> Reconnected After Connection Lost", MESSAGE_CONNECTTOHOST_FAILURE);
      }
      connection_lost_counter = 0;
    }
  }

  if(Timer100msSerialIsOpen) // only when enabled, as this works when serial port is actually connected, but could hang when there is no usb cable to PC
  { while(Serial.available()) 
    { Serial.print(".");
      incomingChar = Serial.read();
      if(incomingChar == '\n')
      { Serial.print("You typed this: ");
        Serial.println(receivedMessage);
        Serial.printf("S-GlobeSettings.btmodule_installed = %d\n", GlobeSettings.btmodule_installed);
        Serial.printf("S-GlobeSettings.btmodule_switchable = %d\n", GlobeSettings.btmodule_switchable);
        strcpy(text, receivedMessage.c_str());
        if((p = strstr(text, "BI")) != 0) 
        { if(text[2]=='0')
          { GlobeSettings.btmodule_installed = 0;
            GlobeSettings.btmodule_switchable = 0;
            digitalWrite(BT_POWER_PIN, LOW);
          }  
          else 
          { GlobeSettings.btmodule_installed = 1;
            digitalWrite(BT_POWER_PIN, HIGH);
          } 
          Serial.printf("BI-GlobeSettings.btmodule_installed = %d\n", GlobeSettings.btmodule_installed);
          Serial.printf("BI-GlobeSettings.btmodule_switchable = %d\n", GlobeSettings.btmodule_switchable);
          EEPROM.put(0x0, GlobeSettings);
          EEPROM.commit();
          Serial.println("Eeprom initialized & saved..");
          sprintf(message, "%d-%d-%d", GlobeSettings.btmodule_switchable, GlobeSettings.btmodule_power_on, GlobeSettings.btmodule_installed);
          AddToQueueForDisplay(message, MESSAGE_DISPLAY_BT_SWITCHABLE_STATE);
        }
        if((p = strstr(text, "BS")) != 0) 
        { Serial.printf("BS-GlobeSettings.btmodule_installed = %d\n", GlobeSettings.btmodule_installed);
          Serial.printf("BS-GlobeSettings.btmodule_switchable = %d\n", GlobeSettings.btmodule_switchable);
          if(text[2]=='0')GlobeSettings.btmodule_switchable = 0;
          else GlobeSettings.btmodule_switchable = 1;
          if(GlobeSettings.btmodule_installed==0)GlobeSettings.btmodule_switchable = 0;
          Serial.printf("BS-GlobeSettings.btmodule_installed = %d\n", GlobeSettings.btmodule_installed);
          Serial.printf("BS-GlobeSettings.btmodule_switchable = %d\n", GlobeSettings.btmodule_switchable);
          EEPROM.put(0x0, GlobeSettings);
          EEPROM.commit();
          Serial.println("Eeprom initialized & saved..");
          sprintf(message, "%d-%d-%d", GlobeSettings.btmodule_switchable, GlobeSettings.btmodule_power_on, GlobeSettings.btmodule_installed);
          AddToQueueForDisplay(message, MESSAGE_DISPLAY_BT_SWITCHABLE_STATE);
        }
        if((p = strstr(text, "SN")) != 0) 
        { Serial.printf("SN-GlobeSettings.serialnumber was = %d\n", GlobeSettings.serialnumber);
          if(strlen(text)>3)
          { sscanf(text,"SN%d", &value_int32t);
            if((value_int32t>50) && (value_int32t<10000)) // valis serial number
            { if(GlobeSettings.serialnumber != value_int32t) // only take action if actually changed
              { GlobeSettings.serialnumber = value_int32t;
                Serial.printf("SN-GlobeSettings.serialnumber stored = %d\n", GlobeSettings.serialnumber);
                EEPROM.put(0x0, GlobeSettings);
                EEPROM.commit();
                Serial.printf("SN-GlobeSettings.serialnumber stored in EEprom = %d\n", GlobeSettings.serialnumber);
                sprintf(text, "%d", GlobeSettings.serialnumber);
                AddToQueueForDisplay(text, MESSAGE_DISPLAY_SERIALNUMBER); // set puck to same serial number
              }
            }
          }  
        }

        receivedMessage = "";
        Serial.printf("->GlobeSettings.btmodule_installed = %d\n", GlobeSettings.btmodule_installed);
        Serial.printf("->GlobeSettings.btmodule_switchable = %d\n", GlobeSettings.btmodule_switchable);
      }
      else
      { receivedMessage += incomingChar;
      }
    }
  }
  
  // process one or more queued messages from display
  while(FromDisplay.QueueIndexIn != FromDisplay.QueueIndexOut) // we have to catch up with new messages
  {  //Serial.printf("Messages from display pending %d\n", FromDisplay.QueueCnt);
     // copy the essential message info into a more readable variable
     QueueMessageType = FromDisplay.QueueMessageType[FromDisplay.QueueIndexOut];
     memcpy(QueueMessage, FromDisplay.QueueMessage[FromDisplay.QueueIndexOut], sizeof(QueueMessage));
     QueueMessage[sizeof(QueueMessage) - 1] = '\0'; // make sure it's 0 terminated

     if((QueueMessageType>=0) && (QueueMessageType<=MESSAGE_MAX)) 
     { Serial.printf("PROCESS: PUCK-SERIAL %d %s >%s<\n", FromDisplay.QueueMessageSerialNumber[FromDisplay.QueueIndexOut], messagetexts[QueueMessageType], QueueMessage); 
     }

     // and now take care of it
     switch(QueueMessageType)
     { case MESSAGE_OPEN_WEATHER_MAP_API_KEY:
         Serial.println(QueueMessage);
         if(strcmp(GlobeSettings.open_weather_map_api_key, QueueMessage)!=0)
         { strcpy(GlobeSettings.open_weather_map_api_key, QueueMessage);
           Serial.println("Eeprom saved -> GlobeSettings.open_weather_map_api_key");
           EEPROM.put(0x0, GlobeSettings);
           EEPROM.commit();
         }
         break;
      
       // puck sends google api key at booting up, could be different from hard coded key, it set in api key file in puck
       case MESSAGE_GOOGLE_API_KEY:
         Serial.println(QueueMessage);
         if(strcmp(GlobeSettings.google_api_key, QueueMessage)!=0)
         { strcpy(GlobeSettings.google_api_key, QueueMessage);
           Serial.println("Eeprom saved -> GlobeSettings.google_api_key");
           EEPROM.put(0x0, GlobeSettings);
           EEPROM.commit();
         }
         break;

       case MESSAGE_THIS_IS_HOME:
         QueueMessage[2]=0; // keep it short
         strcpy(GlobeSettings.HomeCountryCode, QueueMessage);
         EEPROM.put(0x0, GlobeSettings);
         EEPROM.commit();
         Serial.println("Eeprom saved -> GlobeSettings.HomeCountryCode");
         RefreshRatesCountDownTimer = 0; // get new rates immediately
         break;
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

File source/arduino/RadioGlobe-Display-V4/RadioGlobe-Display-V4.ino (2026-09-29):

// Using LVGL with Arduino requires some extra steps...
// Be sure to read the docs here: https://docs.lvgl.io/master/get-started/platforms/arduino.html  */
// Place lv_conf.h (in arduino sketch folder) -> #define LV_MEM_SIZE (68U * 1024U)  /*[bytes]*/  // FB was 48U - remember to change to 68U
// lvgl by kisvegaborn 8.3.11 , not a more recent version, SquareLine Studio only does 8.3.11
// Boards manager, esp32 by Expressif Systems, V3.3.7 with ESP32S3 Dev Module 
// 10APR2026 Boards Manager (trying 3.3.7 now, Waveshare ESP32-S3-Touch-LCD-2.1)
// 10APR2025 In lv_conf.h (root lib folder)-> #define LV_MEM_SIZE (60U * 1024U)  /*[bytes]*/  // FB was 48U - display crashes with 48, maybe increase even more if we keep adding objects???
// 14APR2026 Boards Manager (trying 3.3.8 now, Waveshare ESP32-S3-Touch-LCD-2.1) -> graphics (flag and other things) go bad
// 14APR2026 Boards Manager (back to 3.3.7, Waveshare ESP32-S3-Touch-LCD-2.1) (seems to give glitches in display brightness)
// 14APR2026 Boards Manager (back to 3.3.6, Waveshare ESP32-S3-Touch-LCD-2.1) (still gives glitches in display brightness)
// 14APR2026 Boards Manager (back to 3.3.6, ESP32S3 Dev Module 16MB 3MB app PSRAM OPI) (testing, also still gives glitches in display brightness)
// 14APR2026 Boards Manager (back to 3.3.3, ESP32S3 Dev Module 16MB 3MB app PSRAM OPI) (testing..., also still gives glitches in display brightness)
// 14APR2026 Boards Manager (back to 3.3.7, Waveshare ESP32-S3-Touch-LCD-2.1) (seems to give gfixedsplay luminance)brightness
// 14APR2026 Boards Manager (back to 3.3.7, ESP32S3 Dev Module 16MB 4MB app (custom partition, as program grew > 3MB) PSRAM OPI)) 

// 7 AUG 26 -> pimped colors, MUSIC GLOBE mode (long press RADIO GLOBE to enter) with funny image of jukebox. Tap jukebox to skip to next song
// 1 AUG 26 -> added a flight radar for fun, open it by touching weather icon
// 14 JUL 26 -> added battery level status on preset screen
// 4 JUL 26 -> changed lcd driver frequency from 16Mhz to 14Mhz (hope it fixes the odd screen glithtes) in Display_7701.h
// 4 JUL 26 -> greater click area around flag and power icon on clock face
// 29 JUN 26 -> update and FTP features added
// 28 JUN 26 Changed to custom partition table 4MB APP0 / 4MB APP1 / 8MB FFAT
// had to increase as 3MB was too small with the github update/download feature, went from 98% to 103% -> compiler now reports as 19% from 16MB but we need to stay below 25% (4MB)
// stored in project folder as partitions.csv
// choose custom partition in Arduino IDE
// # Name,   Type, SubType, Offset,  Size, Flags
// nvs,      data, nvs,     0x9000,  0x5000,
// otadata,  data, ota,     0xe000,  0x2000,
// app0,     app,  ota_0,   0x10000, 0x400000,
// app1,     app,  ota_1,   0x410000,0x400000,
// ffat,     data, fat,     0x810000,0x7E0000,
// coredump, data, coredump,0xFF0000,0x10000,

// 29 MAY 26 -> Only find and collect stations from one country
// 17 MAR 26 -> Added speaker off icon, during volume value shown, in case speakers are off
// 15 MAR 26 -> EXPERIMENT LVGL_Driver.cpp line 101 -> commented taskdelay again, maybe not neccesairy, eeprom screen glitch fix attempt
// 14 MAR 26 -> FEATURE shadow edges on long/short press buttons, green for just a selection, yellow for storing a change, red for possibly dangerous change
// 14 MAR 26 -> BUG sprintf timezone to get text string for clock, added (size_t) modifiers to uint8_t variables, as this caused rare random crash/reset of puck
// 14 MAR 26 -> BUG removed needless timezone update on clock hour hand change which caused unexplainable random crash/reset of puck every 5-50 minutes or so
// 13 MAR 26 -> IMPROVEMENT find station again after power up, in case globe was moved to new location
// 13 MAR 26 -> FIX revised eeprom stuff, now saves and loads from file on SD preventing display corruption with the real eeprom save function
// 12 MAR 26 -> FEATURE clickable infostation map
// 11 MAR 26 -> IMPROVEMENT improved click/longpressed algoritm
// 11 MAR 26 -> BUG improved roller setting in calibration menu
// 14 FEB 26 -> FEATURE now has wifi channel updated by globe wifi connection

// note to self
// LVGL_Driver.cpp line 101 -> eeprom screen glitch fix attempt -> didn't hurt and didn't fix it

#define LCD_DIAMETER_2P1

#define MBEDTLS_SSL_MAX_CONTENT_LEN 4096

#define BUILD_LABEL "Puck Build"
// want a string like this -> Puck Build Jun 23 2026 - 21:08:50
#define BUILD_TIMESTAMP  BUILD_LABEL " " __DATE__ " - " __TIME__
#define BUILD_TIMESTAMP_ONLY __DATE__ " - " __TIME__
const char build_label[] =  BUILD_LABEL;
const char build_timestamp[] PROGMEM =  BUILD_TIMESTAMP;
const char build_timestamp_only[] =  BUILD_TIMESTAMP_ONLY;
extern uint8_t UpdateFirmware(uint8_t state); // start with 1 for a full date/time check and update
extern char Wifi_SSID[];
extern char Wifi_PASSWORD[];

#include "..\secrets.h"

// as defined in ..\secrets.h
// char SSID [32] = "YOUR-SSID";
// char PASSWORD[32] = "YOUR-WIFI-PASSWORD";
// char google_api_key[] = "YOUR-API-KEY"; // free, get your own at google developer platform, used for timezone retrieval, replace first 4 letters AIza in !!!!
// to avoid a verbatim copy of api key in compiled binary 

// https://console.cloud.google.com/google/maps-apis/credentials?project=subtle-backup-498313-s5
// https://console.cloud.google.com/apis/dashboard?project=subtle-backup-498313-s5
// char open_weather_map_api_key[] = "YOUR-API-KEY"; // free, get  your own at https://openweathermap.org/api

#define LV_CONF_INCLUDE_SIMPLE // forces LVGL to search for lv_conf.h in sketch folder
#include "lv_conf.h"          
#include <lvgl.h>    

#include "Wireless.h"
#include "Gyro_QMI8658.h"
#include "RTC_PCF85063.h"
#include "SD_Card.h"
#include "LVGL_Driver.h"
#include "BAT_Driver.h"

#include "ui.h"
#include "ui_additional_widgets.h"

#include <WiFi.h>
#include <esp_wifi.h>
#include <WiFiClient.h>
//#include <NetworkClientSecure.h>


#include <ArduinoJson.h>
#include <ArduinoJson.hpp>
#include "franks-esp-now.h"
#include "database.h"
#include "favorites.h"

#include <EEPROM.h>
#define EEPROM_SIZE 4096

#include <ctype.h>
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

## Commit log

2026-07-01 Revise updates in README for clarity and formatting
    Updated README with new features and improvements, including updates for the stations150K.json file and ESP32_VS1053_Stream library.
2026-07-27 Revise README with latest updates and features
    Updated README with new features and improvements for the Radio Globe project, including updates on station URLs, timezone handling, auto power off, and web server functionality.
2026-08-14 Update README for ESP32S3 and feature improvements
2026-09-30 Update README with assembly and setup instructions
    Added detailed instructions for preparing 3D files and ESP32 module setup.
2026-09-30 Create KiCad
2026-09-30 Add files via upload
    PCB files
